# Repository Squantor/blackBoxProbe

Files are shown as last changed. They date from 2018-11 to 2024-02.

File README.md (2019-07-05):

# Black Box probes
This repository contains some hardware reimplementations of the [black magic probe](https://github.com/blacksphere/blackmagic/wiki).
## Structure
* Hardware contains schematics and PCB's
## Checking out
This project makes extensive use of submodules, use ```git clone --recurse-submodules https://github.com/Squantor/$(PROJECT).git``` to clone the repository and its submodules in one go.

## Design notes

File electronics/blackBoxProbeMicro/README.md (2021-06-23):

# BlackBoxProbe Micro variant
A boxed clone of the 
[black magic probe](https://github.com/blacksphere/blackmagic/wiki). The 
black magic probe hardware is good but I would like something more then just a bare PCB and a more suitable connector for the serial connection. This project is here to solve that need. 
Do note, support the people at blacksphere technologies by buying their excellent probe. 
I have made this probe to have a nicer boxed version that I can use. This version has mostly 0402 components and is housed in a smaller box.
## TODO
* production of PCB at Oshpark
* Testing
* pictures
* writeup
## BOM
* [Hammond 1551M](http://www.hammondmfg.com/pdf/1551M.pdf)
* STM32F103
## Pictures
TODO

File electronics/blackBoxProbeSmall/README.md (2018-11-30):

# blackBoxProbe Small variant
A boxed clone of the 
[black magic probe](https://github.com/blacksphere/blackmagic/wiki). The 
black magic probe hardware is good but I would like something more then just a bare PCB. This project is here to solve that need. 
Do note, support the people at blacksphere technologies by buying their excellent probe. 
I have made this probe to have a nicer boxed version that I can use. This version has mostly 0402 components and is housed in a smaller box.
## DONE
* Schematic entry, copied from [black magic probe V2.1](https://github.com/blacksphere/blackmagic/wiki/files/bmpm_v2_1c_schematic.pdf).
## In progress
* Layout, board outline matches a [Hammond 1551G](http://www.hammondmfg.com/pdf/1551G.pdf)
## TODO
* production of PCB+stencils
* Testing
* pictures
* writeup
## BOM
TODO
## Pictures
TODO

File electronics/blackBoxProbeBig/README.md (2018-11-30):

# blackBoxProbe
A boxed clone of the [black magic probe](https://github.com/blacksphere/blackmagic/wiki). The black magic probe hardware is good but I would like something more then just a bare PCB. This project is here to solve that need. 
Do note, support the people at blacksphere technologies by buying their excellent probe. 
I have made this probe to have a nicer boxed version that I can use and is somewhat easier to solder as it only contains 0603 and components with legs like QFP's or TSSOP's. This does make it a bit bigger.
## DONE
* Schematic entry, copied from [black magic probe V2.1](https://github.com/blacksphere/blackmagic/wiki/files/bmpm_v2_1c_schematic.pdf).
* Layout completed, board outline matches a [Hammond 1551R](http://www.hammondmfg.com/pdf/1551R.pdf)
## In progress
* Wait for one day before respinning
## TODO
* Production of PCB's and stencil
* Tests and fixes
* pictures
* writeup
* Smaller boxed version that fits a [hammond 1551G](http://www.hammondmfg.com/pdf/1551G.pdf)
## BOM

## Pictures

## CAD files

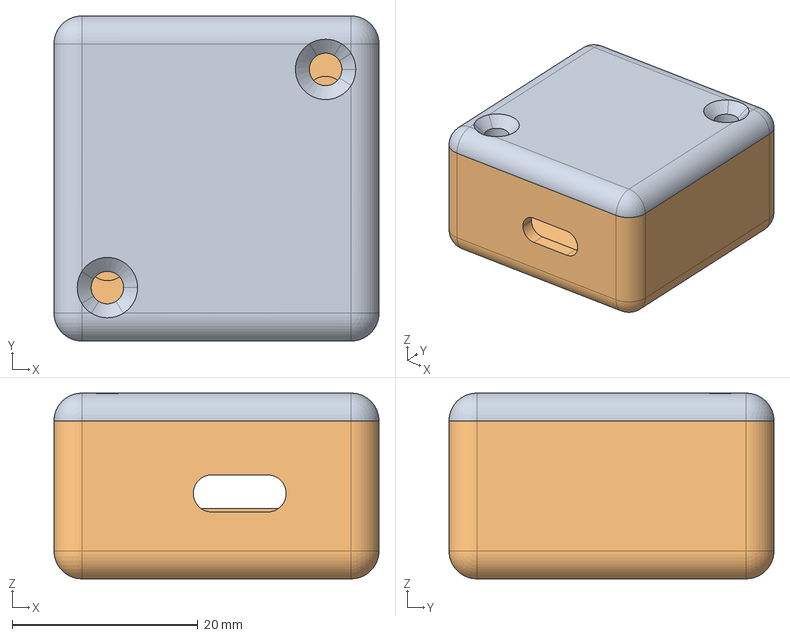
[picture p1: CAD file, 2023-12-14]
mechanical/blackBoxProbeMicro/blackBoxProbeMicro.FCStd
35.0 x 35.0 x 20.0 mm
box_cover
box_body

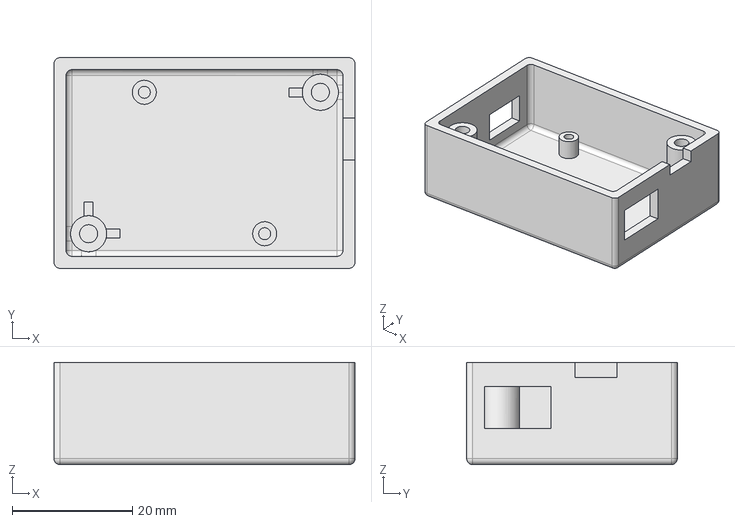
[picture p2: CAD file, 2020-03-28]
mechanical/blackBoxProbeSmall/blackBoxProbeSmall_body.FCStd
50.0 x 35.0 x 17.0 mm

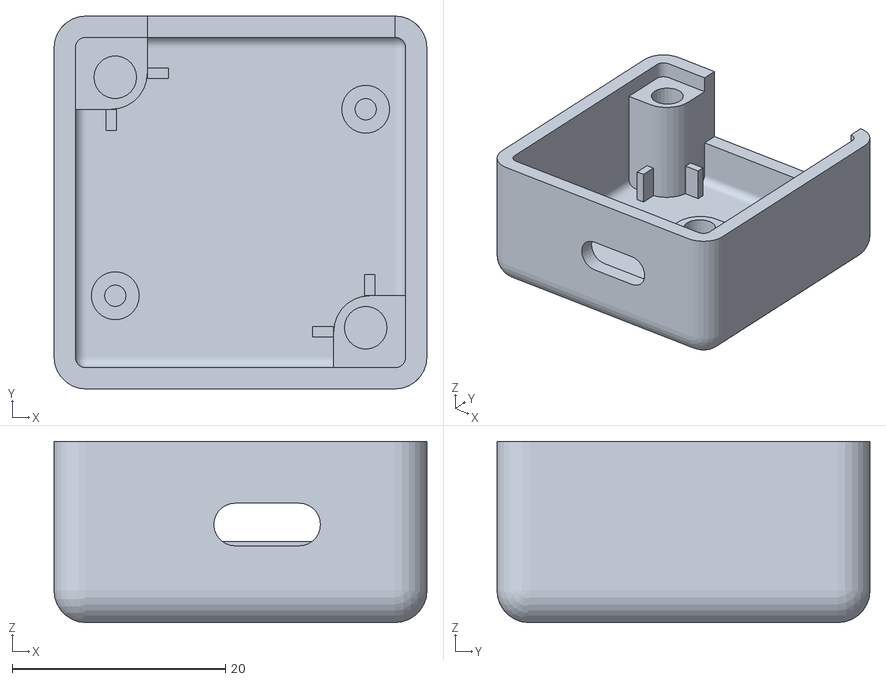
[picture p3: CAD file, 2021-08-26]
mechanical/blackBoxProbeMicro/blackBoxProbeMicro-box_body.stl
35.0 x 35.0 x 17.0

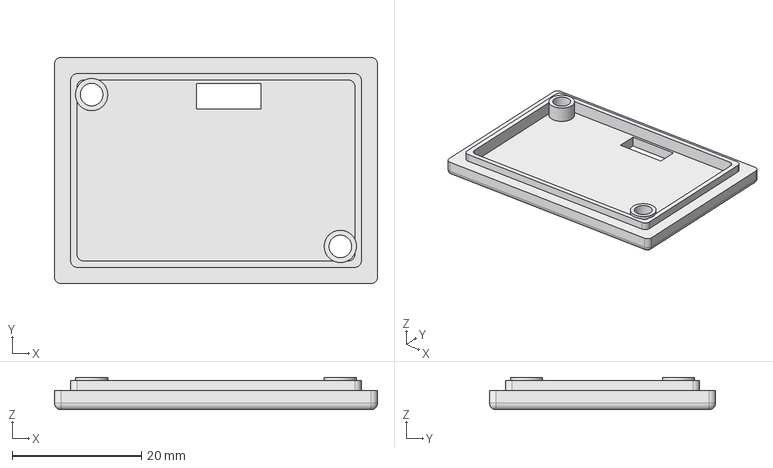
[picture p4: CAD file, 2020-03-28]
mechanical/blackBoxProbeSmall/blackBoxProbeSmall_cover.FCStd
50.0 x 35.0 x 5.00 mm

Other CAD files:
mechanical/blackBoxProbeSmall/blackBoxProbeSmall_body.stl
mechanical/blackBoxProbeSmall/blackBoxProbeSmall_cover.stl

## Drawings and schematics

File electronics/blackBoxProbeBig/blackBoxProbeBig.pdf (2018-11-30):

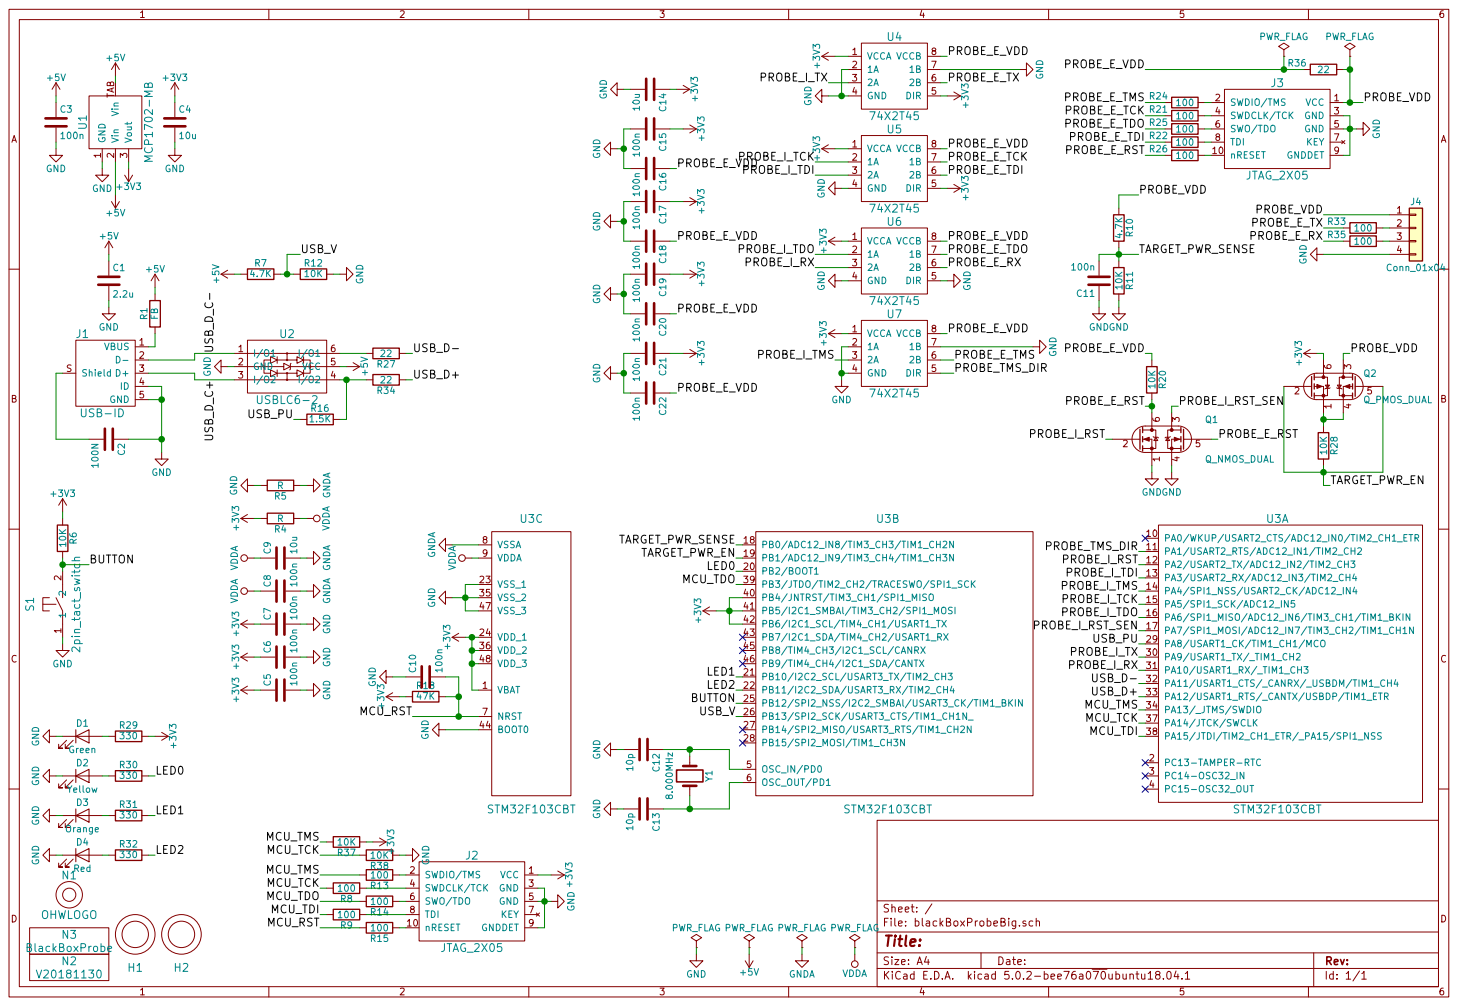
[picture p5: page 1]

2 Vout 3 Vin TAB U1 MCP1702-MB

File: blackBoxProbeBig.sch Sheet: / N2 V20181130 N1 OHWLOGO

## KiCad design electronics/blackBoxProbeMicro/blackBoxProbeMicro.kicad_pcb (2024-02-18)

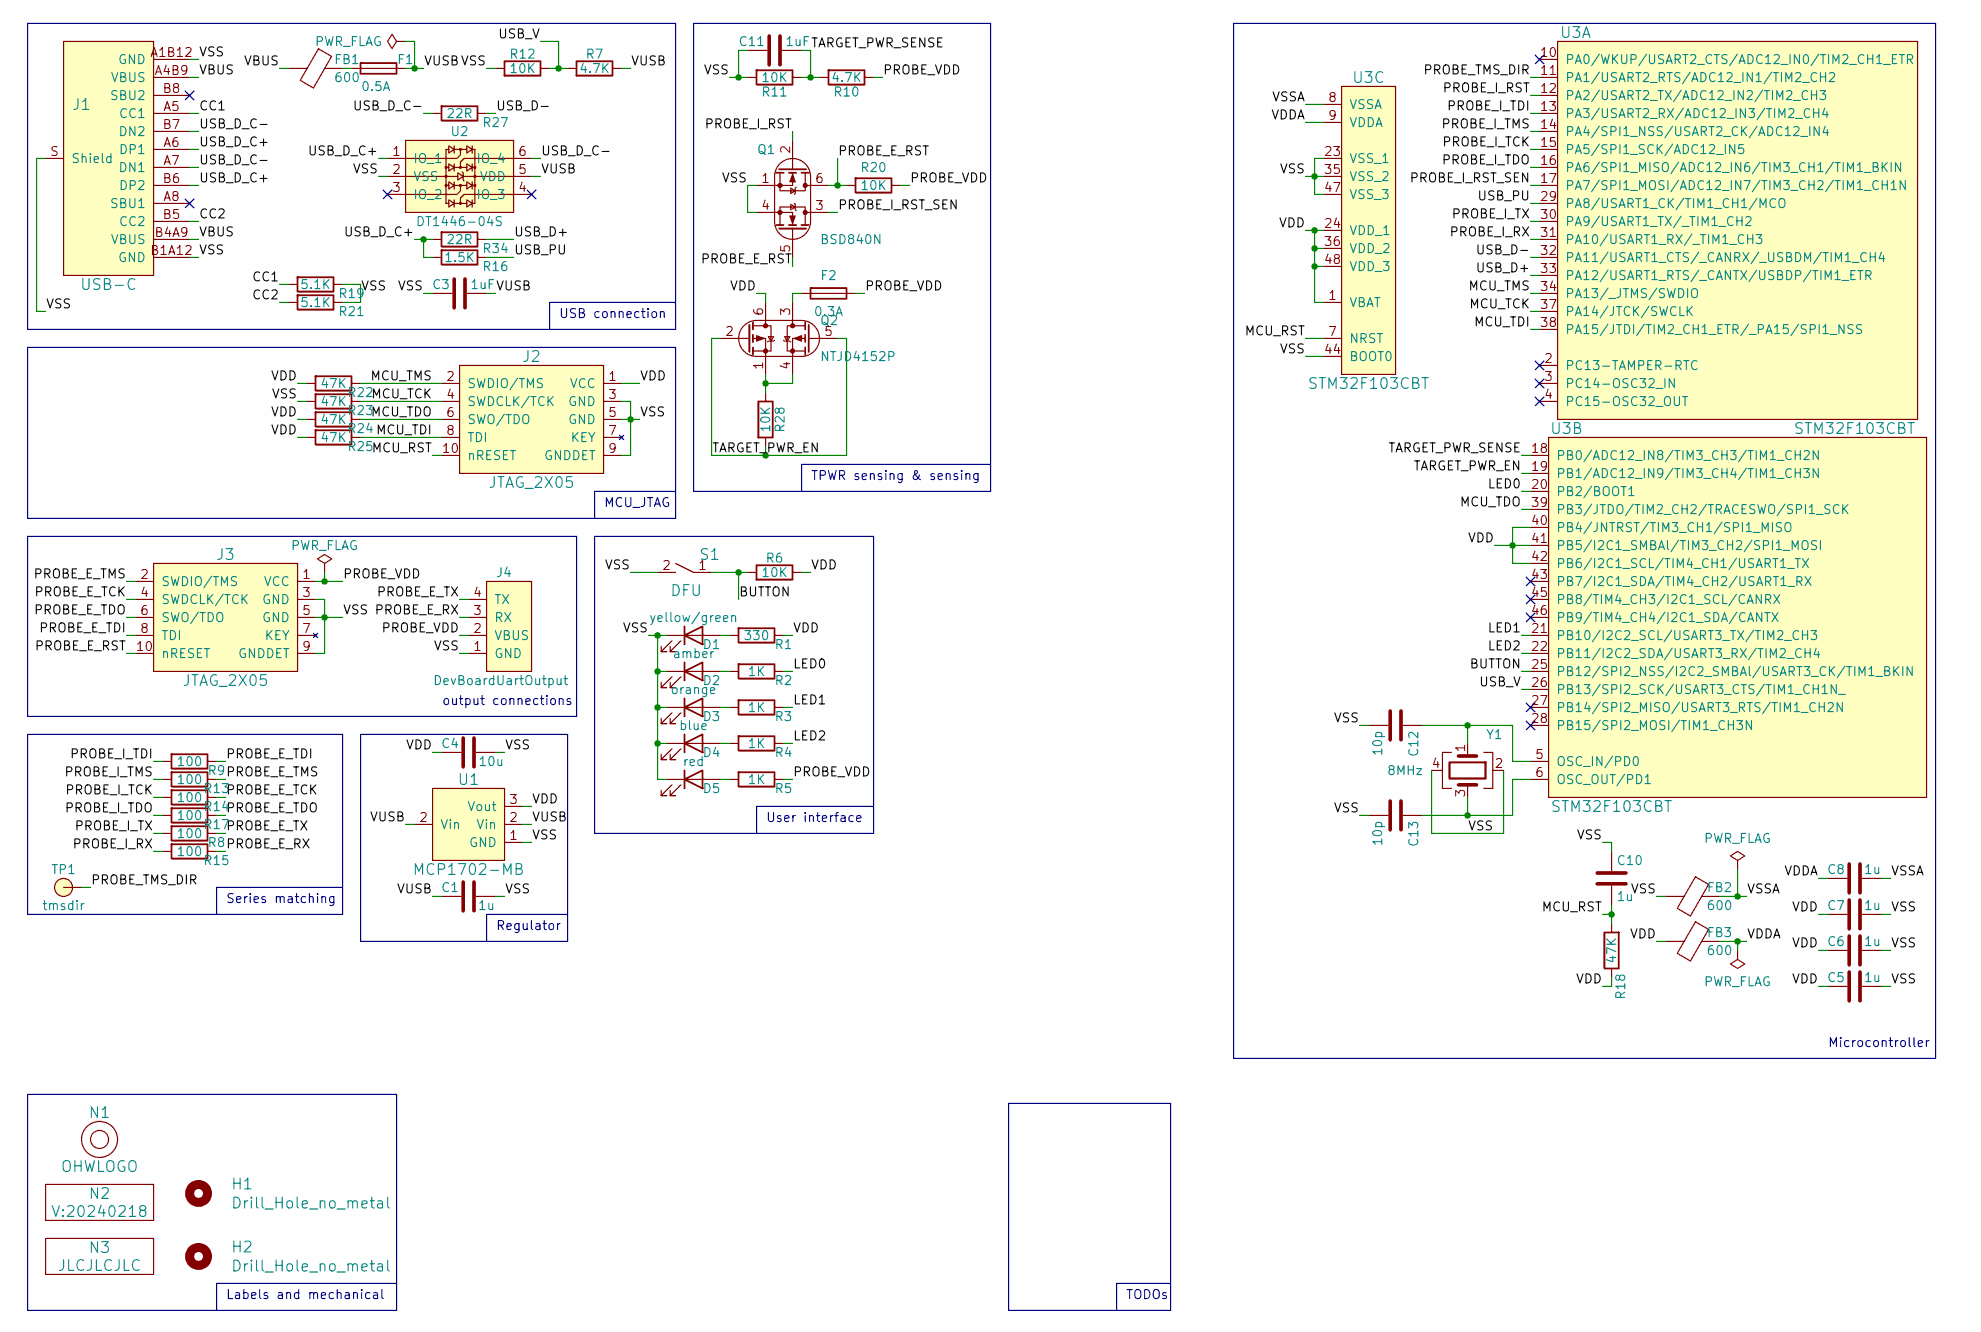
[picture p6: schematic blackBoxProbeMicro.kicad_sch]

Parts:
C1: 1u; C_0603
C3, C11: 1uF; C_0402
C4: 10u; C_0603
C5, C6, C7, C8, C10: 1u; C_0402
C12, C13: 10p; C_0402
D1: yellow/green; LED_0603_hand
D2: amber; LED_0603_hand
D3: orange; LED_0603_hand
D4: blue; LED_0603_hand
D5: red; LED_0603_hand
F1: 0.5A; F_0603_hand
F2: 0.3A; F_0603_hand
FB1: 600; L_0603
FB2, FB3: 600; L_0402
H1, H2: Drill_Hole_no_metal; MountingHole_2.5mm_no_metal
J1: USB-C; USB-C-HRO-31-M-12
J2, J3: JTAG_2X05; Header-0127-2X05-H006
J4: DevBoardUartOutput; JST_PH_S4B-PH-K_1x04_P2.00mm_Horizontal
N1: OHWLOGO; OSHW-Symbol_6.7x6mm_SilkScreen
N2: V:20240218; Label_Generic
N3: JLCJLCJLC; Label_Generic
Q1: BSD840N; SOT363-ONsemi
Q2: NTJD4152P; SOT363-ONsemi
R1: 330; R_0402_hand
R2, R3, R4, R5: 1K; R_0402_hand
R6, R11, R12, R20, R28: 10K; R_0402_hand
R7, R10: 4.7K; R_0402_hand
R8, R9, R13, R14, R15, R17: 100; R_0402_hand
R16: 1.5K; R_0402_hand
R18, R22, R23, R24, R25: 47K; R_0402_hand
R19, R21: 5.1K; R_0402_hand
R27, R34: 22R; R_0402_hand
S1: DFU; TD-85XU
TP1: tmsdir; TestPoint_hole_H03R07
U1: MCP1702-MB; SOT89-NXP
U2: DT1446-04S; SOT363-DiodesInc
U3: STM32F103CBT; LQFP48-STM
Y1: 8MHz; Crystal_3225_4

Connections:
/BUTTON: R6.2, S1.1, U3.25 (PB12/SPI2_NSS/I2C2_SMBAl/USART3_CK/TIM1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)
/CC1: J1.A5 (CC1), R19.2
/CC2: J1.B5 (CC2), R21.2
/LED0: R2.1, U3.20 (PB2/BOOT1)
/LED1: R3.1, U3.21 (PB10/I2C2_SCL/USART3_TX/TIM2_CH3)
/LED2: R4.1, U3.22 (PB11/I2C2_SDA/USART3_RX/TIM2_CH4)
/MCU_RST: C10.2, J2.10 (nRESET), R18.2, U3.7 (NRST)
/MCU_TCK: J2.4 (SWDCLK/TCK), R23.1, U3.37 (PA14/JTCK/SWCLK)
/MCU_TDI: J2.8 (TDI), R25.1, U3.38 (PA15/JTDI/TIM2_CH1_ETR/_PA15/SPI1_NSS)
/MCU_TDO: J2.6 (SWO/TDO), R24.1, U3.39 (PB3/JTDO/TIM2_CH2/TRACESWO/SPI1_SCK)
/MCU_TMS: J2.2 (SWDIO/TMS), R22.1, U3.34 (PA13/_JTMS/SWDIO)
/PROBE_E_RST: J3.10 (nRESET), Q1.5 (G2), Q1.6 (D1), R20.2
/PROBE_E_RX: J4.3 (RX), R15.1
/PROBE_E_TCK: J3.4 (SWDCLK/TCK), R14.1
/PROBE_E_TDI: J3.8 (TDI), R9.1
/PROBE_E_TDO: J3.6 (SWO/TDO), R17.1
/PROBE_E_TMS: J3.2 (SWDIO/TMS), R13.1
/PROBE_E_TX: J4.4 (TX), R8.1
/PROBE_I_RST: Q1.2 (G1), U3.12 (PA2/USART2_TX/ADC12_IN2/TIM2_CH3)
/PROBE_I_RST_SEN: Q1.3 (D2), U3.17 (PA7/SPI1_MOSI/ADC12_IN7/TIM3_CH2/TIM1_C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)
/PROBE_I_RX: R15.2, U3.31 (PA10/USART1_RX/_TIM1_CH3)
/PROBE_I_TCK: R14.2, U3.15 (PA5/SPI1_SCK/ADC12_IN5)
/PROBE_I_TDI: R9.2, U3.13 (PA3/USART2_RX/ADC12_IN3/TIM2_CH4)
/PROBE_I_TDO: R17.2, U3.16 (PA6/SPI1_MISO/ADC12_IN6/TIM3_CH1/TIM1_B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)
/PROBE_I_TMS: R13.2, U3.14 (PA4/SPI1_NSS/USART2_CK/ADC12_IN4)
/PROBE_I_TX: R8.2, U3.30 (PA9/USART1_TX/_TIM1_CH2)
/PROBE_TMS_DIR: TP1.1, U3.11 (PA1/USART2_RTS/ADC12_IN1/TIM2_CH2)
/PROBE_VDD: F2.1, J3.1 (VCC), J4.2 (VBUS), R5.1, R10.1, R20.1
/TARGET_PWR_EN: Q2.2 (G1), Q2.5 (G2), R28.2, U3.19 (PB1/ADC12_IN9/TIM3_CH4/TIM1_CH3N)
/TARGET_PWR_SENSE: C11.2, R10.2, R11.1, U3.18 (PB0/ADC12_IN8/TIM3_CH3/TIM1_CH2N)
/USB_D+: R34.1, U3.33 (PA12/USART1_RTS/_CANTX/USBDP/TIM1_ETR)
/USB_D-: R27.1, U3.32 (PA11/USART1_CTS/_CANRX/_USBDM/TIM1_CH4)
/USB_D_C+: J1.A6 (DP1), J1.B6 (DP2), R16.2, R34.2, U2.1 (IO_1)
/USB_D_C-: J1.A7 (DN1), J1.B7 (DN2), R27.2, U2.6 (IO_4)
/USB_PU: R16.1, U3.29 (PA8/USART1_CK/TIM1_CH1/MCO)
/USB_V: R7.2, R12.1, U3.26 (PB13/SPI2_SCK/USART3_CTS/TIM1_CH1N_)
/VBUS: FB1.2, J1.A4B9 (VBUS), J1.B4A9 (VBUS)
/VDD: C4.1, C5.1, C6.1, C7.1, FB3.2, J2.1 (VCC), Q2.6 (D1), R1.1, R6.1, R18.1, R22.2, R24.2, R25.2, U1.3 (Vout), U3.1 (VBAT), U3.24 (VDD_1), U3.36 (VDD_2), U3.40 (PB4/JNTRST/TIM3_CH1/SPI1_MISO), U3.41 (PB5/I2C1_SMBAl/TIM3_CH2/SPI1_MOSI), U3.42 (PB6/I2C1_SCL/TIM4_CH1/USART1_TX), U3.48 (VDD_3)
/VDDA: C8.1, FB3.1, U3.9 (VDDA)
/VSS: C1.2, C3.1, C4.2, C5.2, C6.2, C7.2, C10.1, C11.1, C12.2, C13.2, D1.1 (K), D2.1 (K), D3.1 (K), D4.1 (K), D5.1 (K), FB2.2, J1.A1B12 (GND), J1.B1A12 (GND), J1.S (Shield), J2.3 (GND), J2.5 (GND), J2.9 (GNDDET), J3.3 (GND), J3.5 (GND), J3.9 (GNDDET), J4.1 (GND), Q1.1 (S1), Q1.4 (S2), R11.2, R12.2, R19.1, R21.1, R23.2, S1.2, U1.1 (GND), U2.2 (VSS), U3.23 (VSS_1), U3.35 (VSS_2), U3.44 (BOOT0), U3.47 (VSS_3), Y1.2, Y1.4
/VSSA: C8.2, FB2.1, U3.8 (VSSA)
/VUSB: C1.1, C3.2, F1.1, R7.1, U1.2 (Vin), U2.5 (VDD)
unnamed: D1.2 (A), R1.2
unnamed: D2.2 (A), R2.2
unnamed: D3.2 (A), R3.2
unnamed: D4.2 (A), R4.2
unnamed: D5.2 (A), R5.2
unnamed: F1.2, FB1.1
unnamed: F2.2, Q2.3 (D2)
unnamed: Q2.1 (S1), Q2.4 (S2), R28.1
unnamed: C12.1, U3.5 (OSC_IN/PD0), Y1.1
unnamed: C13.1, U3.6 (OSC_OUT/PD1), Y1.3

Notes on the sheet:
Regulator
USB connection
Labels and mechanical
TPWR sensing & sensing
output connections
Series matching
Microcontroller
TODOs
User interface
MCU_JTAG

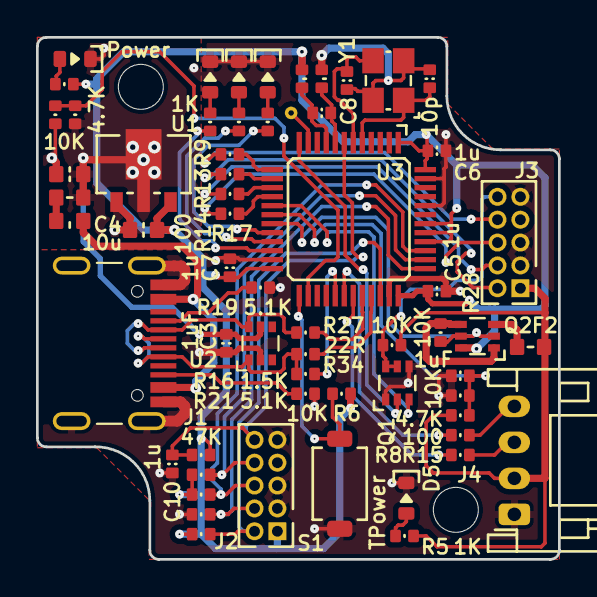
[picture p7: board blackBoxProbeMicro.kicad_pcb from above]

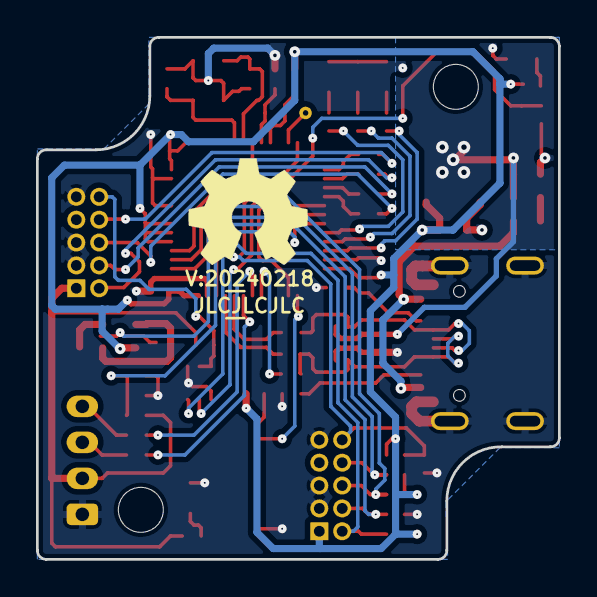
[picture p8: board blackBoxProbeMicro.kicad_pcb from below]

Board: 4 copper layers, 29.0 x 29.0 mm, 66 parts (3 on the bottom side), 52 nets.

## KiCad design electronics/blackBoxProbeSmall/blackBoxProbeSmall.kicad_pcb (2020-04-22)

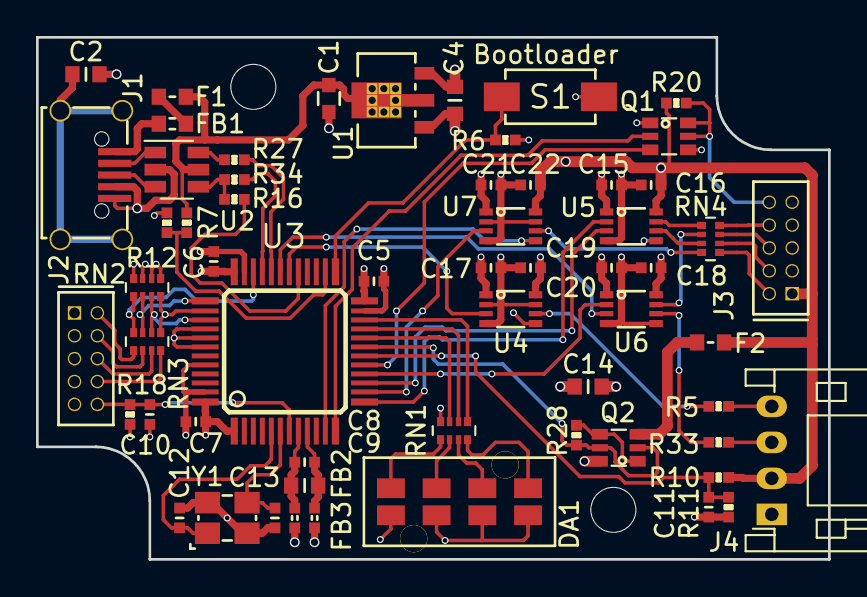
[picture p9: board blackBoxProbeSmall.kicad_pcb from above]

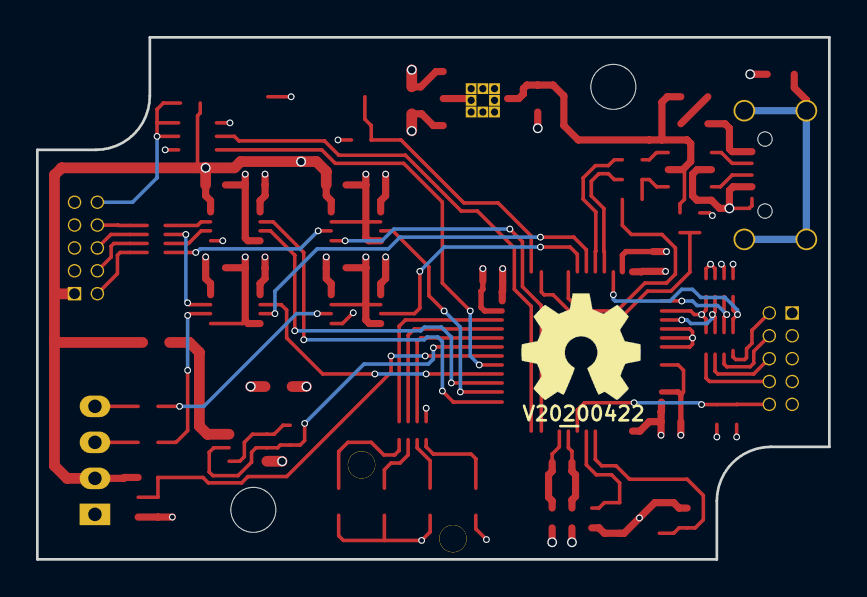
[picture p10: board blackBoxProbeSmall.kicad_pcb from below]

Board: 4 copper layers, 44.0 x 29.0 mm, 63 parts (2 on the bottom side), 62 nets.

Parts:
C1: 1u; C_0603
C2: 100N; C_0603
C4, C9, C14: 10u; C_0603
C5, C6, C7, C8, C10, C15, C16, C17, C18, C19, C20, C21, C22: 1u; C_0402
C11: 1uF; C_0402
C12, C13: 10p; C_0402
DA1: mentor_1296.4124
F1: 0.5A; F_0603_hand
F2: 0.3A; F_0603_hand
FB1: Ferrite_Bead; L_0603
FB2, FB3: Ferrite_Bead; L_0402
H1, H2: Drill_Hole_no_metal; MountingHole_2.5mm_no_metal
J1: USB-ID; USB-muB-SMD_TH
J2, J3: JTAG_2X05; Header-0127-2X05-H006
J4: DevBoardUartOutput; JST_PH_S4B-PH-K_04x2.00mm_Angled
N1: OHWLOGO; OSHW-Symbol_6.7x6mm_SilkScreen
N2: V20200422; Label_Generic
Q1: Q_NMOS_DUAL; SOT363-hand
Q2: Q_PMOS_DUAL; SOT363-hand
R5, R33: 33; R_0402_hand
R6, R11, R12, R20, R28: 10K; R_0402_hand
R7, R10: 4.7K; R_0402_hand
R16: 1.5K; R_0402_hand
R18: 47K; R_0402_hand
R27, R34: 22; R_0402_hand
RN1: 470; R_Array_Convex_4x0402
RN2: 47K; R_Array_Convex_4x0402
RN3, RN4: 33; R_Array_Convex_4x0402
S1: 2pin_tact_switch; DTSM3
U1: MCP1702-MB; SOT89-NXP-Viatab
U2: USBLC6-2; SOT23-6-HAND
U3: STM32F103CBT; SOT313-2
U4, U5, U6, U7: 74X2T45; SOT765-1-NXP
Y1: 8MHz; Crystal_3225_4

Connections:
/BUTTON: R6.2, S1.2, U3.25
/LED0: RN1.7, U3.20
/LED1: RN1.6, U3.21
/LED2: RN1.5, U3.22
/MCU_RST: C10.2, J2.10, R18.2, U3.7
/MCU_TCK: RN2.6, RN3.3, U3.37
/MCU_TDI: RN2.8, RN3.1, U3.38
/MCU_TDO: RN2.7, RN3.2, U3.39
/MCU_TMS: RN2.5, RN3.4, U3.34
/PROBE_E_RST: J3.10, Q1.5, Q1.6, R20.2
/PROBE_E_RX: R33.2, U6.6
/PROBE_E_TCK: RN4.3, U5.6
/PROBE_E_TDI: RN4.1, U5.7
/PROBE_E_TDO: RN4.2, U6.7
/PROBE_E_TMS: RN4.4, U7.6
/PROBE_E_TX: R5.2, U4.6
/PROBE_I_RST: Q1.2, U3.12
/PROBE_I_RST_SEN: Q1.3, U3.17
/PROBE_I_RX: U3.31, U6.3
/PROBE_I_TCK: U3.15, U5.3
/PROBE_I_TDI: U3.13, U5.2
/PROBE_I_TDO: U3.16, U6.2
/PROBE_I_TMS: U3.14, U7.3
/PROBE_I_TX: U3.30, U4.3
/PROBE_TMS_DIR: U3.11, U7.5
/PROBE_VDD: C16.1, C18.1, C20.1, C22.1, F2.1, J3.1, J4.2, R10.1, R20.1, U4.8, U5.8, U6.8, U7.8
/TARGET_PWR_EN: Q2.2, Q2.5, R28.2, U3.19
/TARGET_PWR_SENSE: C11.2, R10.2, R11.1, U3.18
/USB_D+: R34.1, U3.33
/USB_D-: R27.1, U3.32
/USB_D_C+: J1.3, U2.3
/USB_D_C-: J1.2, U2.1
/USB_PU: R16.1, U3.29
/USB_V: R7.2, R12.1, U3.26
/VDD: C4.1, C5.1, C6.1, C7.1, C14.1, C15.1, C17.1, C19.1, C21.1, FB3.2, J2.1, Q2.6, R6.1, R18.1, RN1.8, RN2.1, RN2.2, RN2.4, U1.3, U3.1, U3.24, U3.36, U3.40, U3.41, U3.42, U3.48, U4.1, U4.5, U5.1, U5.5, U6.1, U7.1
/VDDA: C8.1, C9.1, FB3.1, U3.9
/VSS: C1.2, C2.1, C4.2, C5.2, C6.2, C7.2, C10.1, C11.1, C12.2, C13.2, C14.2, C15.2, C16.2, C17.2, C18.2, C19.2, C20.2, C21.2, C22.2, DA1.5, DA1.6, DA1.7, DA1.8, FB2.2, J1.4, J1.5, J2.3, J2.5, J2.9, J3.3, J3.5, J3.9, J4.1, Q1.1, Q1.4, R11.2, R12.2, RN2.3, S1.1, U1.1, U2.2, U3.23, U3.35, U3.44, U3.47, U4.2, U4.4, U4.7, U5.4, U6.4, U6.5, U7.2, U7.4, U7.7, Y1.2, Y1.4
/VSSA: C8.2, C9.2, FB2.1, U3.8
/VUSB: C1.1, F1.1, R7.1, U1.2, U2.5
unnamed: C2.2, J1.S
unnamed: C12.1, U3.5, Y1.1
unnamed: C13.1, U3.6, Y1.3
unnamed: DA1.1, RN1.1
unnamed: DA1.2, RN1.2
unnamed: DA1.3, RN1.3
unnamed: DA1.4, RN1.4
unnamed: F1.2, FB1.1
unnamed: F2.2, Q2.3
unnamed: FB1.2, J1.1
unnamed: J2.2, RN3.5
unnamed: J2.4, RN3.6
unnamed: J2.6, RN3.7
unnamed: J2.8, RN3.8
unnamed: J3.2, RN4.5
unnamed: J3.4, RN4.6
unnamed: J3.6, RN4.7
unnamed: J3.8, RN4.8
unnamed: J4.3, R33.1
unnamed: J4.4, R5.1
unnamed: Q2.1, Q2.4, R28.1
unnamed: R16.2, R34.2, U2.4
unnamed: R27.2, U2.6

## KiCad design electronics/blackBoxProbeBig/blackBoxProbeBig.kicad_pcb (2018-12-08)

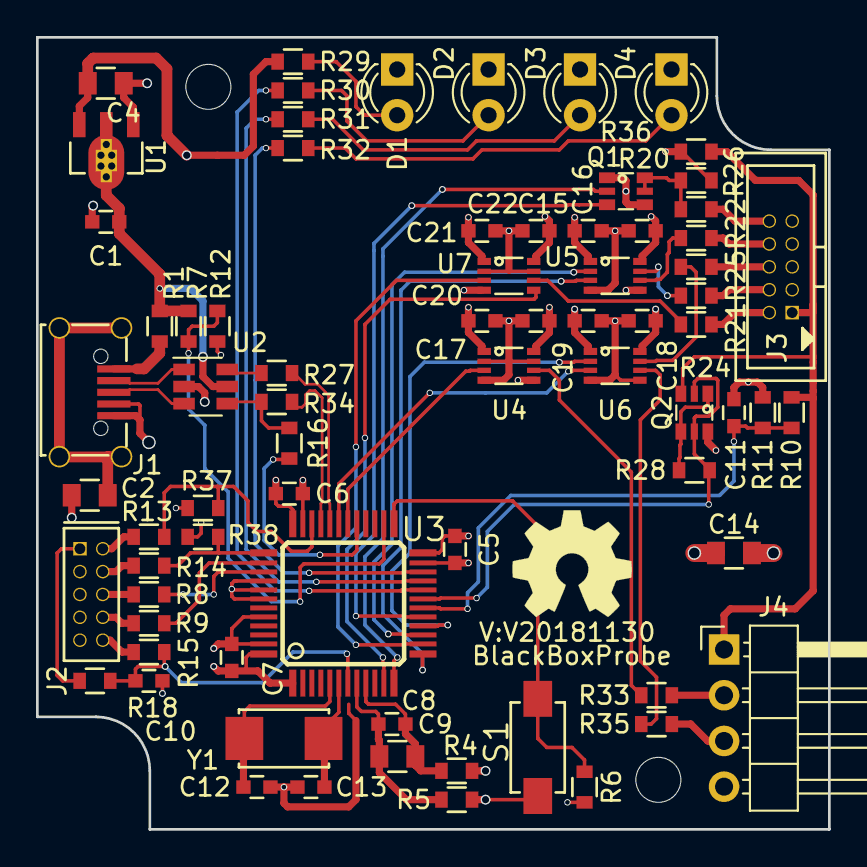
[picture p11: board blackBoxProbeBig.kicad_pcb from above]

Board: 4 copper layers, 44.0 x 44.0 mm, 78 parts (0 on the bottom side), 63 nets.

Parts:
C1: 1u; C_0603
C2: 100N; C_0805
C4, C9, C14: 10u; C_0805
C5, C6, C7, C8, C10, C11, C15, C16, C17, C18, C19, C20, C21, C22: 100n; C_0603
C12, C13: 10p; C_0603
D1: Green; LED_D3.0mm
D2: Yellow; LED_D3.0mm
D3: Orange; LED_D3.0mm
D4: Red; LED_D3.0mm
H1, H2: Drill_Hole_no_metal; MountingHole_2.5mm_no_metal
J1: USB-ID; SquantorUsb-USB-UB-SMD4H
J2: JTAG_2X05; Header-0127-2X05-H006
J3: JTAG_2X05; Header-Shr-0127-2X05-H006
J4: Conn_01x04; Pin_Header_Angled_1x04_Pitch2.54mm
N1: OHWLOGO; OSHW-Symbol_6.7x6mm_SilkScreen
N2: V20181130; Label_version
N3: BlackBoxProbe; Label_version
Q1: Q_NMOS_DUAL; SOT363-hand
Q2: Q_PMOS_DUAL; SOT363-hand
R1: FB; R_0603_hand
R4, R5: R; R_0603_hand
R6, R11, R12, R20, R28, R37, R38: 10K; R_0603_hand
R7, R10: 4.7K; R_0603_hand
R8, R9, R13, R14, R15, R21, R22, R24, R25, R26, R33, R35: 100; R_0603_hand
R16: 1.5K; R_0603_hand
R18: 47K; R_0603_hand
R27, R34, R36: 22; R_0603_hand
R29, R30, R31, R32: 330; R_0603_hand
S1: 2pin_tact_switch; DTSM3
U1: MCP1702-MB; SOT89-ViaTab-Microchip-MB
U2: USBLC6-2; SOT23-6-HAND
U3: STM32F103CBT; SOT313-2
U4, U5, U6, U7: 74X2T45; SOT765-1-NXP
Y1: 8.000MHz; X_5.0_3.2

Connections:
+3V3: C4.1, C5.1, C6.1, C7.1, C14.1, C15.1, C17.1, C19.1, C21.1, J2.1, Q2.6, R4.2, R6.1, R18.1, R29.2, R37.1, U1.3, U3.1, U3.24, U3.36, U3.40, U3.41, U3.42, U3.48, U4.1, U4.5, U5.1, U5.5, U6.1, U7.1
+5V: C1.1, R1.2, R7.1, U1.2, U1.TAB, U2.5
/BUTTON: R6.2, S1.2, U3.25
/LED0: R30.2, U3.20
/LED1: R31.2, U3.21
/LED2: R32.2, U3.22
/MCU_RST: C10.2, R15.2, R18.2, U3.7
/MCU_TCK: R8.2, R38.2, U3.37
/MCU_TDI: R9.2, U3.38
/MCU_TDO: R14.2, U3.39
/MCU_TMS: R13.2, R37.2, U3.34
/PROBE_E_RST: Q1.5, Q1.6, R20.2, R26.2
/PROBE_E_RX: R35.2, U6.6
/PROBE_E_TCK: R21.2, U5.7
/PROBE_E_TDI: R22.2, U5.6
/PROBE_E_TDO: R25.2, U6.7
/PROBE_E_TMS: R24.2, U7.6
/PROBE_E_TX: R33.2, U4.6
/PROBE_E_VDD: C16.1, C18.1, C20.1, C22.1, R20.1, R36.2, U4.8, U5.8, U6.8, U7.8
/PROBE_I_RST: Q1.2, U3.12
/PROBE_I_RST_SEN: Q1.3, U3.17
/PROBE_I_RX: U3.31, U6.3
/PROBE_I_TCK: U3.15, U5.2
/PROBE_I_TDI: U3.13, U5.3
/PROBE_I_TDO: U3.16, U6.2
/PROBE_I_TMS: U3.14, U7.3
/PROBE_I_TX: U3.30, U4.3
/PROBE_TMS_DIR: U3.11, U7.5
/PROBE_VDD: J3.1, J4.1, Q2.3, R10.1, R36.1
/TARGET_PWR_EN: Q2.2, Q2.5, R28.2, U3.19
/TARGET_PWR_SENSE: C11.2, R10.2, R11.1, U3.18
/USB_D+: R34.1, U3.33
/USB_D-: R27.1, U3.32
/USB_D_C+: J1.3, U2.3
/USB_D_C-: J1.2, U2.1
/USB_PU: R16.1, U3.29
/USB_V: R7.2, R12.1, U3.26
GND: C1.2, C2.1, C4.2, C5.2, C6.2, C7.2, C10.1, C11.1, C12.2, C13.2, C14.2, C15.2, C16.2, C17.2, C18.2, C19.2, C20.2, C21.2, C22.2, D1.1, D2.1, D3.1, D4.1, J1.4, J1.5, J2.3, J2.5, J2.9, J3.3, J3.5, J3.9, J4.4, Q1.1, Q1.4, R5.2, R11.2, R12.2, R38.1, S1.1, U1.1, U2.2, U3.23, U3.35, U3.44, U3.47, U4.2, U4.4, U4.7, U5.4, U6.4, U6.5, U7.2, U7.4, U7.7
GNDA: C8.2, C9.2, R5.1, U3.8
unnamed: C2.2, J1.S
unnamed: C12.1, U3.5, Y1.1
unnamed: C13.1, U3.6, Y1.2
unnamed: D1.2, R29.1
unnamed: D2.2, R30.1
unnamed: D3.2, R31.1
unnamed: D4.2, R32.1
unnamed: J1.1, R1.1
unnamed: J2.2, R13.1
unnamed: J2.4, R8.1
unnamed: J2.6, R14.1
unnamed: J2.8, R9.1
unnamed: J2.10, R15.1
unnamed: J3.2, R24.1
unnamed: J3.4, R21.1
unnamed: J3.6, R25.1
unnamed: J3.8, R22.1
unnamed: J3.10, R26.1
unnamed: J4.2, R33.1
unnamed: J4.3, R35.1
unnamed: Q2.1, Q2.4, R28.1
unnamed: R16.2, R34.2, U2.4
unnamed: R27.2, U2.6
VDDA: C8.1, C9.1, R4.1, U3.9

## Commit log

2018-03-30 * added blackboxprobe project based on PP40 bottom PCB 4 layer
    [blackBoxProbe.kicad_pcb, blackBoxProbe.sch]
2018-03-30 * schematic layout of usb input and powersupply * PCB placing of usb input and powersupply
    [blackBoxProbe.kicad_pcb, blackBoxProbe.sch]
2018-04-03 * added usb protection diode
    [blackBoxProbe.sch]
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2018-04-16 * placed controller and schematic entry of microcontroller power
    [blackBoxProbe.sch]
2018-06-13 DONE: switched over case to hammond 1551G
    [blackBoxProbe.kicad_pcb]
2018-06-13 WIP: further copying of the black box probe schematic
    [blackBoxProbe.sch]
2018-06-14 WIP: added JTAG/SWD interface bits, still reset sensing needs to be done
    [blackBoxProbe.sch]
2018-06-14 DONE: Finished schematic WIP: review WIP: Assign components
    [blackBoxProbe.sch]
2018-06-21 FIX: fixed wrong schematic symbol for the switch, needs to be dual PMOS DONE: assigned all components a footprint
    [blackBoxProbe.sch]
2018-06-21 DONE: imported netlist to PCB WIP: initial placing, thinking about replacing all R and C by 0402
    [blackBoxProbe.kicad_pcb, blackBoxProbe.sch]
2018-06-22 WIP: Switching to bigger case
    [blackBoxProbe.kicad_pcb]
2018-06-22 DONE: switched to new PCB layout WIP: rough component placement
    [blackBoxProbe.kicad_pcb]
2018-06-22 WIP: initial placement of all the components, start the tetris music!
    [blackBoxProbe.kicad_pcb, blackBoxProbe.sch]
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2018-06-23 FIX: fixed boot0 pulldown to something stronger WIP: further component placement WIP: need to replace JTAG headers to TH headers
    [blackBoxProbe.kicad_pcb, blackBoxProbe.sch]
2018-06-23 DONE: tuned USB differential pair length WIP: inital layouting WIP: further optimal placing
    [blackBoxProbe.kicad_pcb, blackBoxProbe.sch]
2018-06-24 WIP: More routing DONE: optimization of components, removing redudant/superflous components WIP: more optimal placement, maybe I can fit this in a 44 by 30mm box?
    [blackBoxProbe.kicad_pcb, blackBoxProbe.sch]
2018-06-24 WIP: Futher layout, done power switch, reset circuit
    [blackBoxProbe.kicad_pcb]
2018-06-24 WIP: additional routing WIP: placed the level shifting network WIP: Further component optimization and removal
    [blackBoxProbe.kicad_pcb, blackBoxProbe.sch]
2018-06-24 DONE: routing of all nets, visual check still needed
    [blackBoxProbe.kicad_pcb]
2018-06-24 FIX: incorrect pin mapping of STM32 DONE: changed to 3mm leds, plenty of space DONE: routing WIP: Silk/value placing
    [blackBoxProbe.kicad_pcb, blackBoxProbe.sch]
2018-06-24 DONE: placed all the silkscreen designations
    [blackBoxProbe.kicad_pcb]
2018-06-24 FIX: forgotten one disconnected net
    [blackBoxProbe.kicad_pcb]
2018-06-24 DONE: fixed crystal layout DONE: added a guard trace to isolate crystal from VSSA
    [blackBoxProbe.kicad_pcb, blackBoxProbe.sch]
2018-06-25 FIX: incorrect naming of 74X2T45 gate FIX: missing USB series resistors FIX: added another label for the project name
    [blackBoxProbe.kicad_pcb, blackBoxProbe.sch]
2018-06-25 DONE: rerouted everything after fixing the pinout of the header
    [blackBoxProbe.kicad_pcb, blackBoxProbe.sch]
2018-06-26 WIP: final placement of silk, need some checks
    [blackBoxProbe.kicad_pcb]
2018-06-26 DONE: Silk placement ready for production, let it sit for one day
    [blackBoxProbe.kicad_pcb]
2018-06-27 DONE: last silk screen modifications
    [blackBoxProbe.kicad_pcb]
2018-06-27 DONE: more silkscreen position changes
    [blackBoxProbe.kicad_pcb]
2018-06-27 DONE: actualised plotting settings
    [blackBoxProbe.kicad_pcb]
2018-06-27 DONE: updated version number
    [blackBoxProbe.kicad_pcb, blackBoxProbe.sch]
2018-06-27 DONE: add gerbers sent to the fab
    [blackBoxProbe-B.Cu.gbr, blackBoxProbe-B.Mask.gbr, blackBoxProbe-B.SilkS.gbr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]
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2018-07-15 fixed errors and some minor modifications
    [blackBoxProbe.sch]
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2018-07-15 fixed decoupling of the level shifters on the probe side
    [blackBoxProbe.sch]
2018-07-15 placed and routed all components/airwires
    [blackBoxProbe.kicad_pcb]
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2018-07-15 additional changes to layout and some traces
    [blackBoxProbe.kicad_pcb]
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2018-07-16 updated gerbers to V20180716
    [blackBoxProbe-B.Cu.gbr, blackBoxProbe-B.Mask.gbr, blackBoxProbe-B.SilkS.gbr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]
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2018-07-28 renaming blackBoxProbe to the big variant with hammond 1551R
    [blackBoxProbeBig-B.Cu.gbr, blackBoxProbeBig-B.Mask.gbr, blackBoxProbeBig-B.SilkS.gbr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]
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2018-07-28 replaced all R's C's and inserted new box outline
    [blackBoxProbeSmall.kicad_pcb, blackBoxProbeSmall.sch]
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2018-11-30 simplified schematic to be more in line with black magic probe v2.1
    [blackBoxProbeBig.sch]
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2018-11-30 schematic simplifications, regulator rework, silk movements
    [blackBoxProbeBig.kicad_pcb, blackBoxProbeBig.sch]
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2018-12-08 further placement of components, everything fits on pcb, now compacting due to smaller footprints
    [blackBoxProbeSmall.kicad_pcb, blackBoxProbeSmall.sch]
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2019-08-04 reduced crystal size, replaced 0805 with 0603
    [blackBoxProbeSmall.kicad_pcb, blackBoxProbeSmall.sch]
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2019-08-15 switching from global nets to sheet wide nets
    [blackBoxProbeSmall.sch]
2019-08-15 imported changes into PCB to check 3d models
    [blackBoxProbeSmall.kicad_pcb, blackBoxProbeSmall.sch]
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2019-08-19 more layout and some silk placement, need to move the microcontroller closer to the programming header to create more space
    [blackBoxProbeSmall.kicad_pcb]
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2020-01-31 some placement fixes, silk fixes and changed paste aperatures
    [blackBoxProbeSmall.kicad_pcb]
2020-02-02 silk placement mistakes fixed, removed groundplane under crystal
    [blackBoxProbeSmall.kicad_pcb]
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2020-03-27 changed position of component values to ease assembly
    [blackBoxProbeSmall.kicad_pcb]
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2020-04-10 moved some components away from screw hole, updated versionnumber
    [blackBoxProbeSmall.kicad_pcb, blackBoxProbeSmall.sch]
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2021-06-15 renamed to be consistent with general project structure
    [blackBoxProbeBig.kicad_pcb, blackBoxProbeBig.sch, blackBoxProbeSmall.kicad_pcb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]
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2021-06-15 reworking schematic
    [blackBoxProbeMicro.kicad_pcb, blackBoxProbeMicro.sch]
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2021-06-15 initial placement, schematic changes, change to 4 layer board
    [blackBoxProbeMicro.kicad_pcb, blackBoxProbeMicro.sch]
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2021-06-19 changed label footprint, further routing and minor placement improvements
    [blackBoxProbeMicro.kicad_pcb, blackBoxProbeMicro.sch]
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2021-06-20 changed design rules to match 4 layer specs, passing DRC, silk placement
    [blackBoxProbeMicro.kicad_pcb]
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2021-06-30 replaced all resistor networks with 0402 resistors, removed SWD series resistors for programming the main MCU, changed series resistors for the programming interface, updated versionnumber
    [blackBoxProbeMicro.sch]
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2021-06-30 some silk placement, and component replacement to accomodate silk
    [blackBoxProbeMicro.kicad_pcb]
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2021-08-18 fixed incorrect path to footprint library
2021-08-18 changed ESD diode to something smaller and cheaper
    [blackBoxProbeMicro.kicad_pcb, blackBoxProbeMicro.sch]
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2021-08-26 removed ground plane underneath crystal oscillator section
    [blackBoxProbeMicro.kicad_pcb, blackBoxProbeMicro.sch]
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2021-08-26 moved JTAG out connector a bit from the edge
    [blackBoxProbeMicro.kicad_pcb]
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2023-02-24 fixing ERC/DRC errors after component updates
    [blackBoxProbeMicro.kicad_pcb, blackBoxProbeMicro.kicad_sch]
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2023-12-14 enabled visibility of lid of the blackbox micro box
    [blackBoxProbeMicro.FCStd]
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2024-01-17 WIP updating parts and PCB, replacing silk parts
    [blackBoxProbeMicro.kicad_pcb, blackBoxProbeMicro.kicad_sch]
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2024-01-21 adjustments of silk, fixing ERC errors
    [blackBoxProbeMicro.kicad_pcb, blackBoxProbeMicro.kicad_sch]
2024-02-02 all planes are now VSS planes, some routing improvements
    [blackBoxProbeMicro.kicad_pcb, blackBoxProbeMicro.kicad_sch]
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
